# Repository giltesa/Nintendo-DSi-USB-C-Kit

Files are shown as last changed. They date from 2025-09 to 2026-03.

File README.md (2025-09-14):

# Nintendo DSi USB-C

The **Nintendo DSi: USB-C** is a board that allows to replace the original charging connector for a modern and standard **USB-C**.

**If your original connector is too old or damaged** and you need a new one, or **if you would like to charge your Nintendo DSi with a standard USB-C charger**, like the charger of your **Nintendo Switch**, phone, laptop, you can with this board.

This board is compatible with these models:

*   Nintendo DSi
*   Nintendo DSi XL

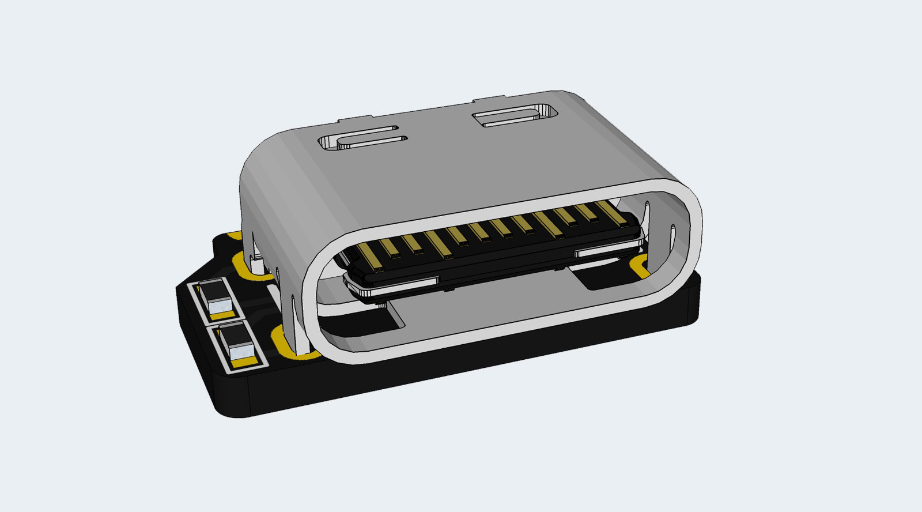
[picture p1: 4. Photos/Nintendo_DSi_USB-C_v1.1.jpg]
Nintendo-DSi-USB-C


## Would you like it?

https://shop.giltesa.com/product/nintendo-DSi-usb-c-kit/

## More

- [giltesa.com](https://giltesa.com "giltesa.com")
- [twitter.com](https://twitter.com/giltesa "twitter.com")

## License

This project is licensed under a **Creative Commons** license:
**[Attribution-NonCommercial-ShareAlike 4.0 International (CC BY-NC-SA 4.0) ](https://creativecommons.org/licenses/by-nc-sa/4.0/)**

Check the [LICENSE.md](LICENSE.md) for more information.

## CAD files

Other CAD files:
2. Renders, 3D models/Nintendo DSi USB-C - DATA v1.0.skp
2. Renders, 3D models/Nintendo DSi USB-C v1.0.skp
2. Renders, 3D models/Nintendo DSi USB-C v1.1.skp

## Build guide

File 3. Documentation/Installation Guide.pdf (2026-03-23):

# USB-C KIT For

# Nintendo DSi Nintendo DSi XL

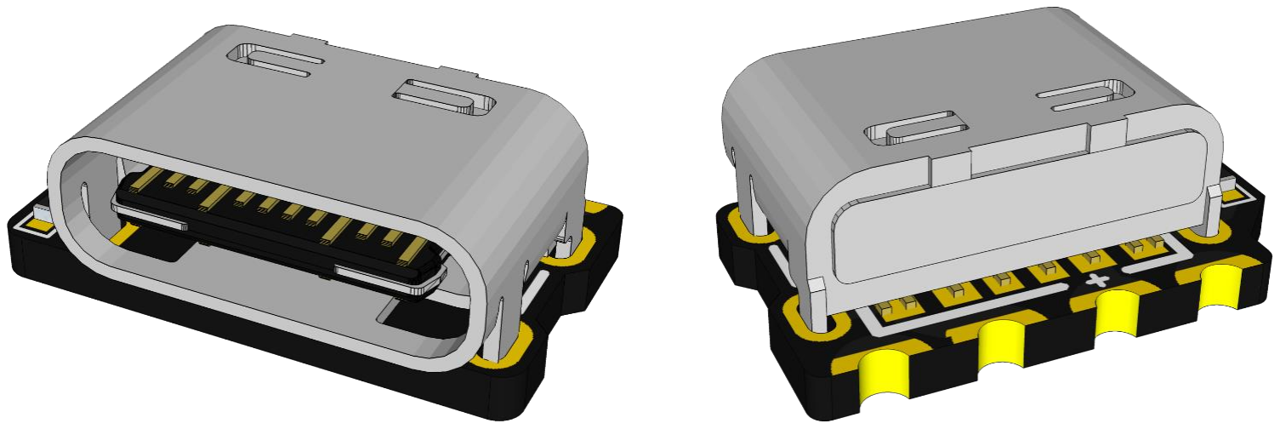
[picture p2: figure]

### PRODUCT

HTTPS://SHOP.GILTESA.COM/PRODUCT/NINTENDO-DSi-USB-C-KIT

# PLEASE READ THROUGH THESE INSTRUCTIONS

ENTIRELY BEFORE ATTEMPTING TO INSTALL.

# WARNING: IF YOU ARE NOT COMFORTABLE WITH SOLDERING, OR PERFORMING ANY STEP IN THIS

GUIDE, DO NOT PERFORM THE INSTALL YOURSELF.

# FIND SOMEONE WHO IS COMFORTABLE TO DO IT FOR

YOU.

INDEX

# Description

The Nintendo DSi: USB-C Kit is a board that allows to replace the original charging connector for a modern and standard USB-C.

If your original connector is too old or damaged and you need a new one, or if you would like to charge your Nintendo DSi with a standard USB-C charger, like the charger of your Nintendo Switch, phone, laptop, you can with this kit.

This board is compatible with these two models:

- Nintendo DSi
- Nintendo DSi XL

# FEATURES

- Charging your Nintendo with:
- USB power banks
- USB-A chargers
- USB-C chargers
- USB-C PD chargers (normal speed, not fast)
- USB-A to USB-C cables
- USB-C to USB-C cables

# INCLUDED

- 1 board.

# Recommended / REQUIRED (NOT INCLUDED)

- Phillips screwdriver
- Kapton tape
- Soldering iron
- Tin
- Flux
- Desoldering pump
- Desoldering mesh
- Isopropyl alcohol

# Board details

This tiny board has 7 pads in about 1cm²
surface, which means it requires high soldering skills. The following explains what each pad is for.

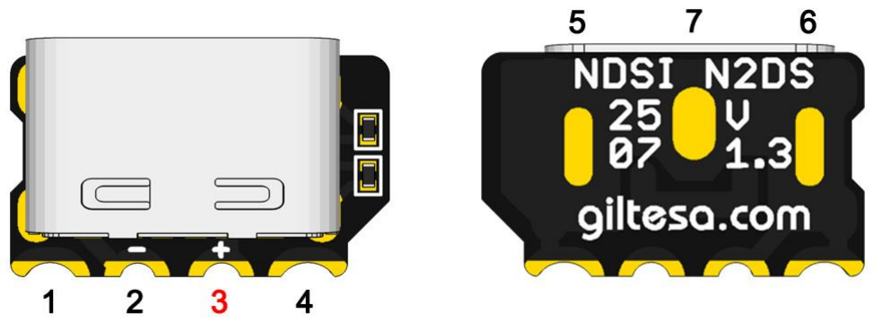
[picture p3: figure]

Nintendo DSi - Standard version.

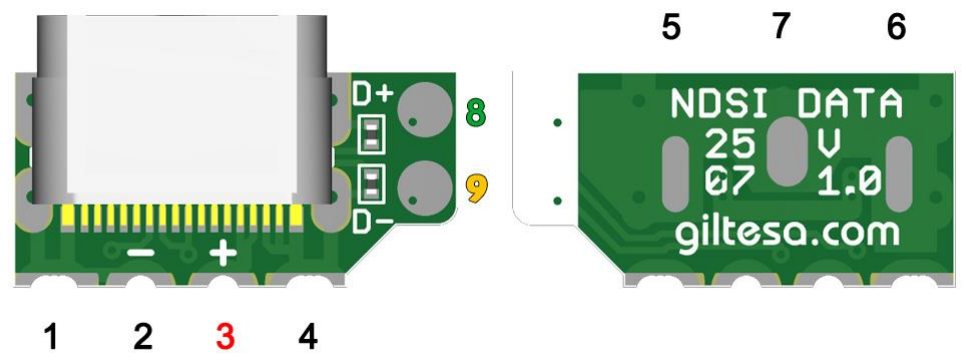
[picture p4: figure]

Nintendo 3DS DATA - With support for data connection.

Starting from the left to the right:

1. GND | The ground pad.
2. GND | The ground pad.
3. VCC | The 5V line from the USB-C.
4. GND | The ground pad.
5. GND | The ground pad.
6. GND | The ground pad.
7. GND | This ground pad is exclusive to the 2DS. Do not use it on
| the DSi.
8. D+ | Positive data pad for only DATA board model.
9. D- | Negative data pad for only DATA board model.

# Test the board!

Before starting the installation, you should test the board. If it doesn’t work contact me for a replacement (https://shop.giltesa.com/refund-policy/) (all boards are fully tested, but they may damage during the shipping, we try to package them as better as possible), if it works, go ahead with the installation.

Connect the power from your USB charger to the USB-C connector on the board. Then, with a multimeter in voltage measurement mode, check for a 5V reading. If that's the case, continue with the installation.

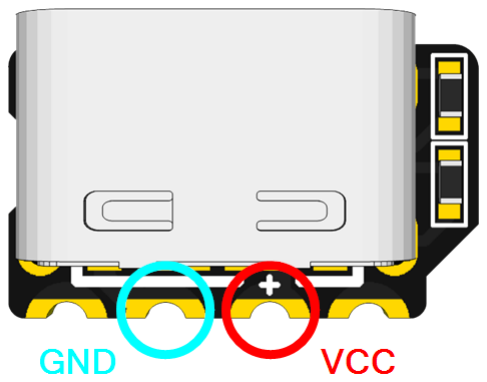
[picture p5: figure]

# INSTALLATION STEPS

Please, carefully read the following steps for a successful installation.

## Pre installation Steps

Before the installation, your Nintendo DSi may need some extra steps to have it ready for the kit.

1. Disassembly the Nintendo DSi

Nintendo DSi use the phillips screws to close the shell. First remove the two screws which hold the DSi plastic battery cover.

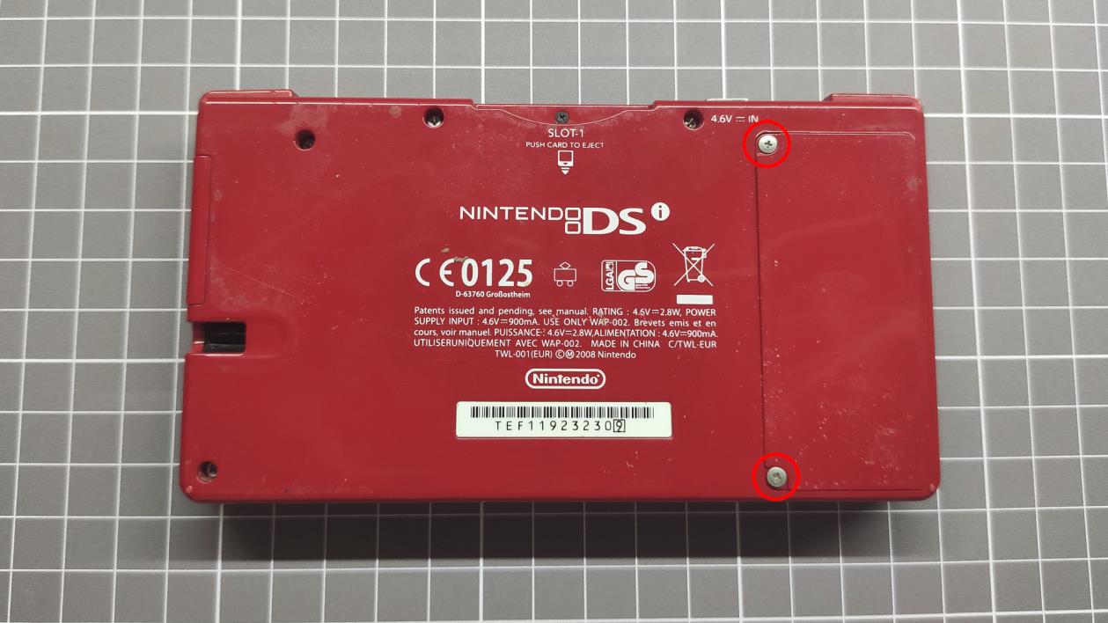
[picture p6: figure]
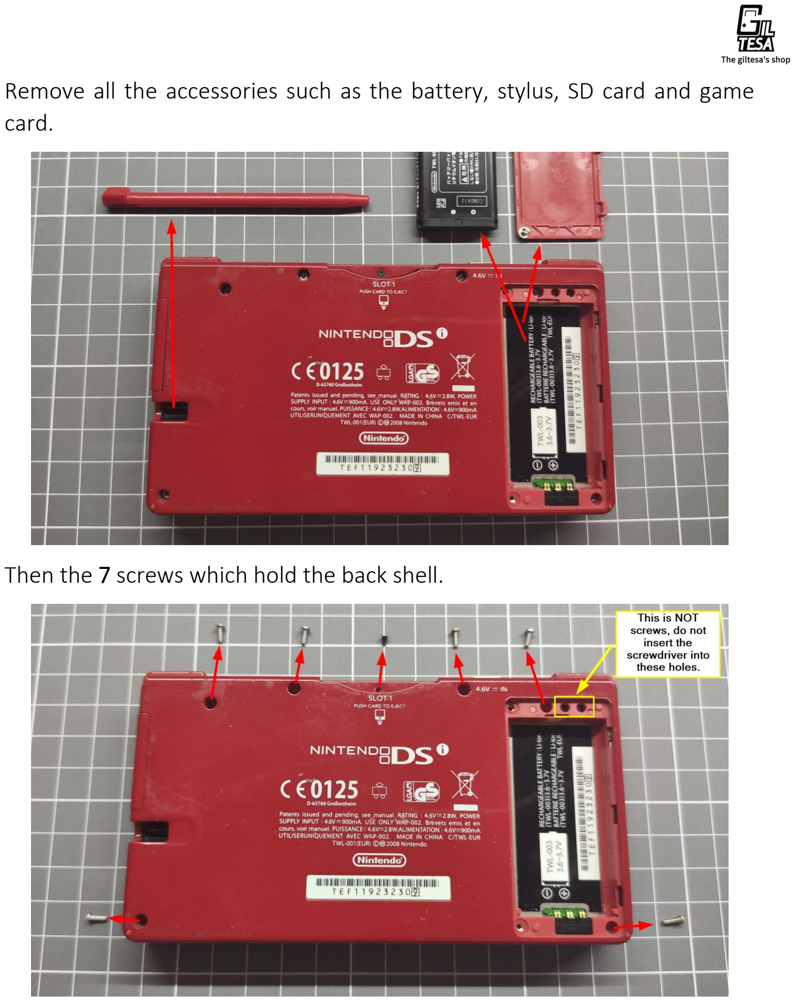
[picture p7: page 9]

Remove all the accessories such as the battery, stylus, SD card and game card.

Then the 7 screws which hold the back shell.

Open the back shell carefully because it is connected to the mainboard with one flex cable. To disconnect the flex cable, pull it upwards.

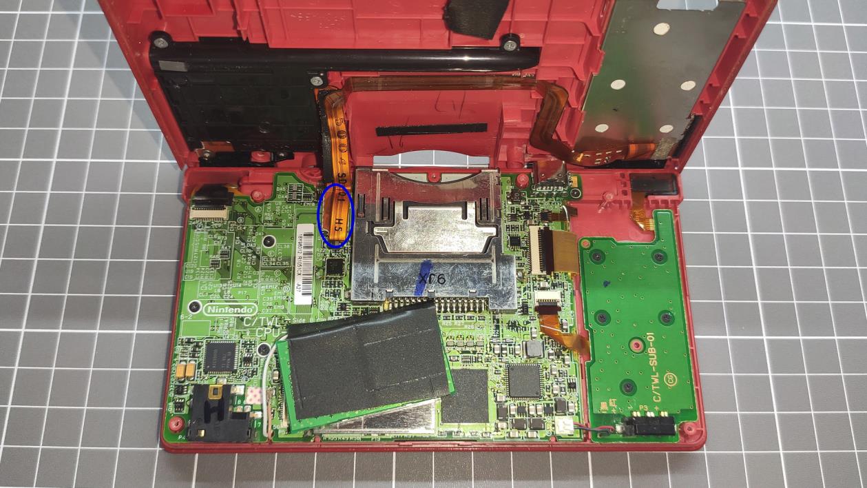
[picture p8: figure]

As you can see in the images, my Nintendo DSi already had the kit installed. I lost the photos when I was removing the original connector, but that's not a problem since it's removed in the same way.

So, I'm going to remove my test kit and install the final version, and you will have to remove the original connector and install the kit.

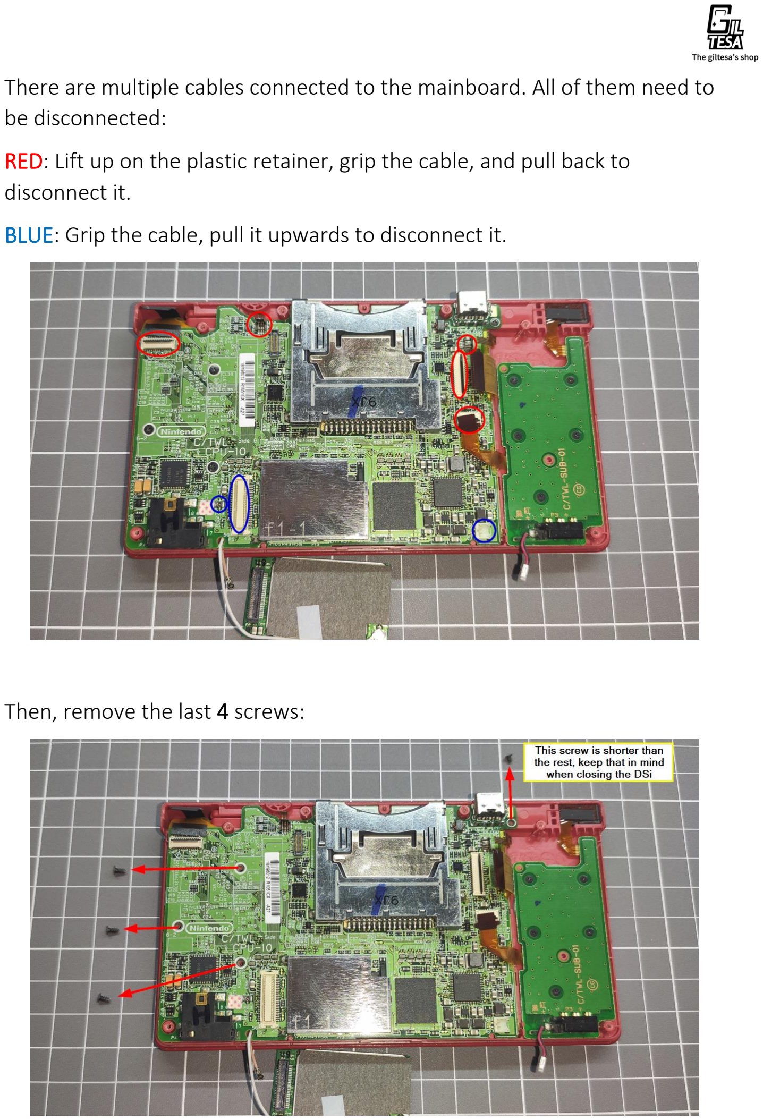
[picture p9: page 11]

There are multiple cables connected to the mainboard. All of them need to be disconnected:

RED: Lift up on the plastic retainer, grip the cable, and pull back to disconnect it.

BLUE: Grip the cable, pull it upwards to disconnect it.

Then, remove the last 4 screws:

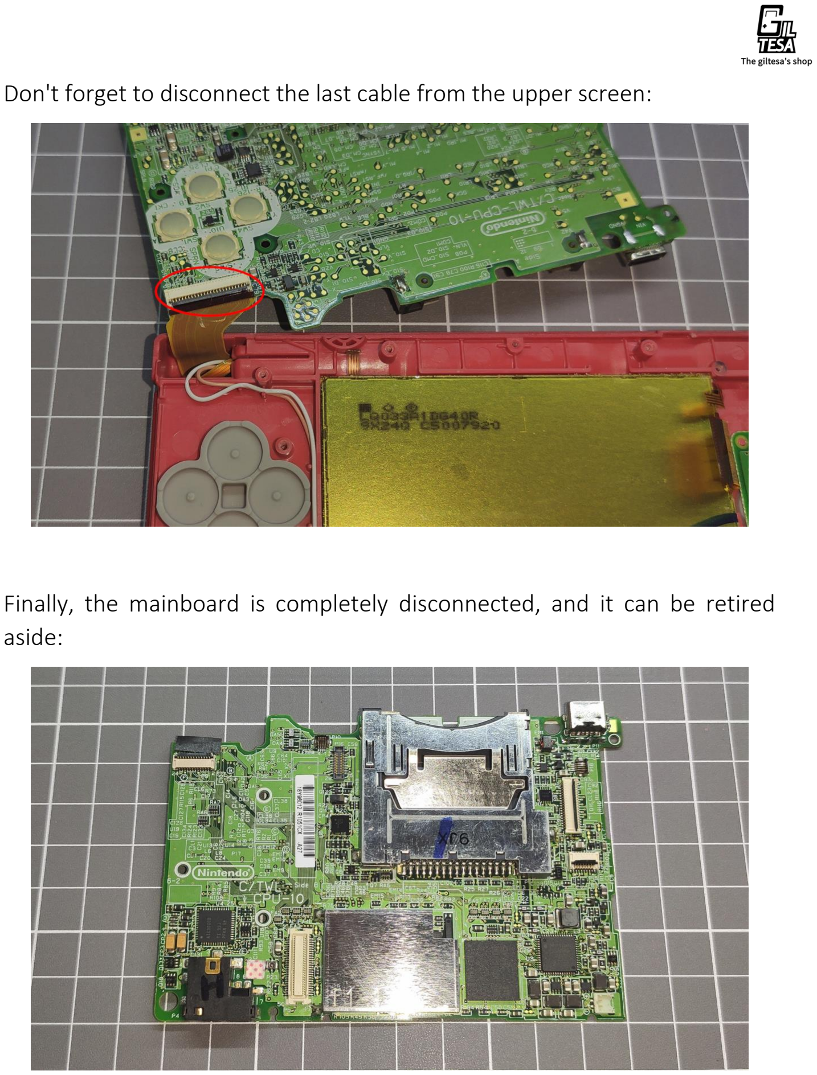
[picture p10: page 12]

Don't forget to disconnect the last cable from the upper screen:

Finally, the mainboard is completely disconnected, and it can be retired aside:

## installation Steps

1. Protect the nearest components

Use Kapton tape to protect and avoid any damage to the electronic components that are next to the connector.

2. Remove unnecessary components

This kit only requires removing the power connector. However, it has many legs, and it may be hard to remove.

If you have an air solder station, you can remove it easily, but protect perfect the nearest places with Kapton tape or something may be burn.

Otherwise, the recommendation is using a desoldering pump which will help to remove the tin from each hole/pad.

3. Clean the board

After the component is removed, it may be dirty, clean both sides.

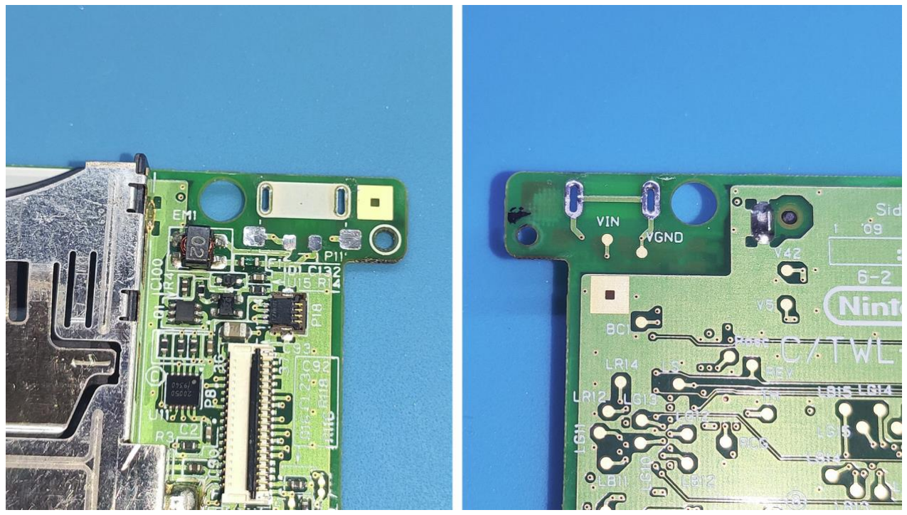
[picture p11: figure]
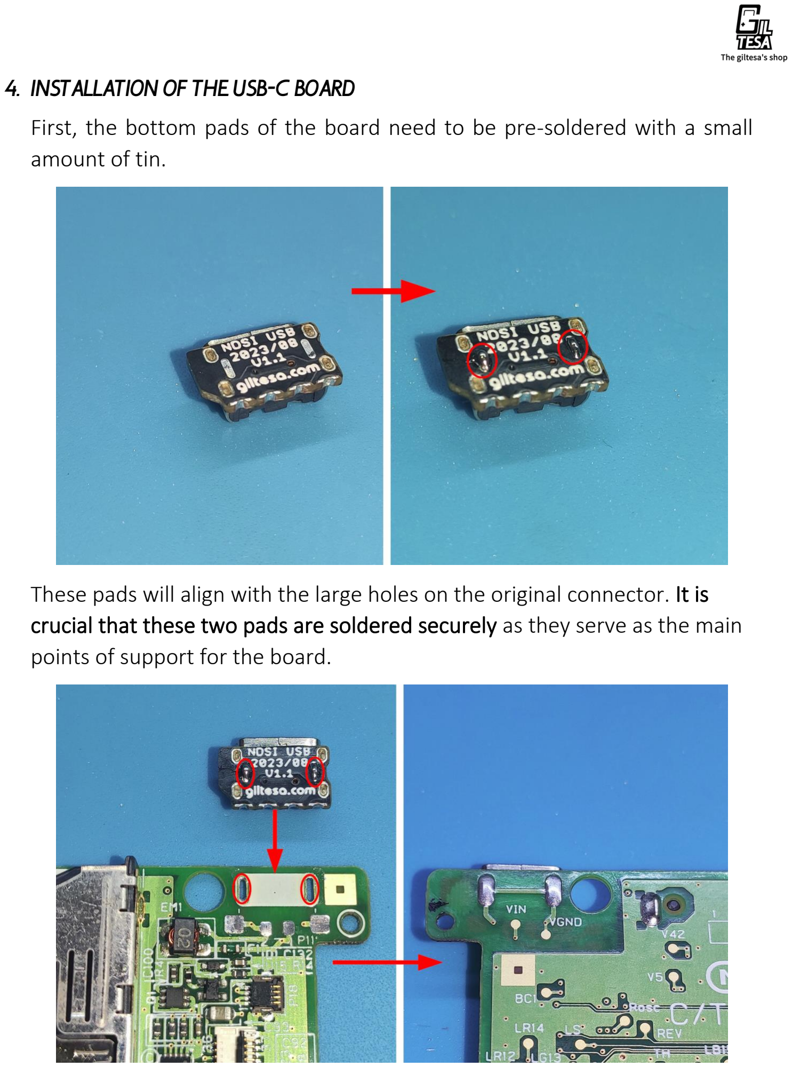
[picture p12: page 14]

4. Installation of the USB-C board

First, the bottom pads of the board need to be pre-soldered with a small amount of tin.

These pads will align with the large holes on the original connector. It is crucial that these two pads are soldered securely as they serve as the main points of support for the board.

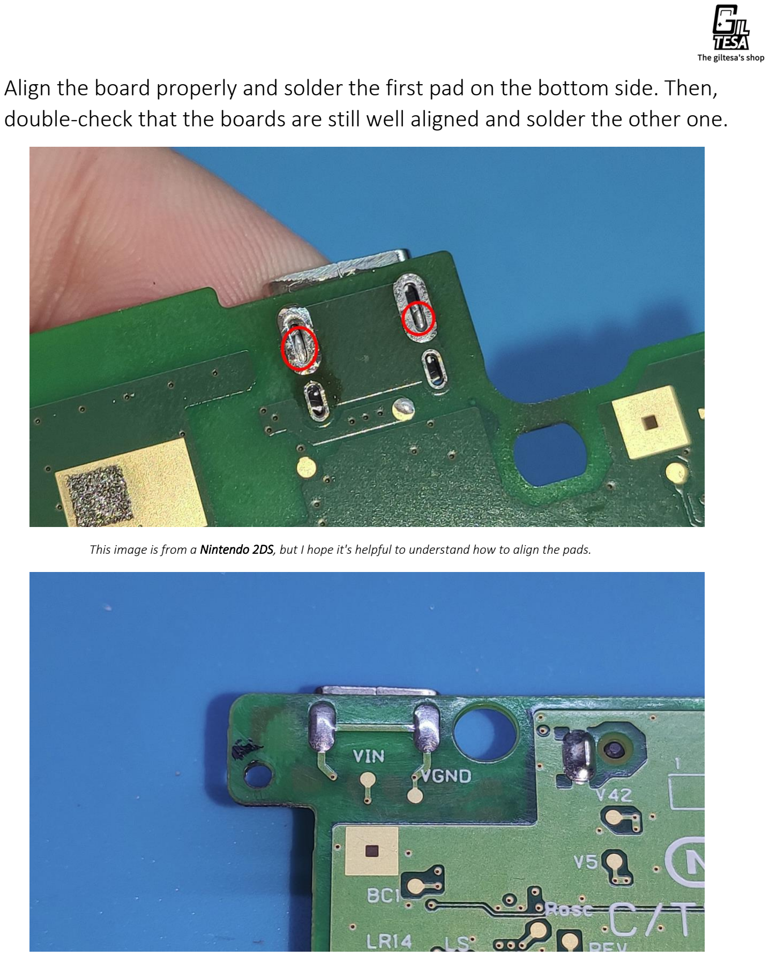
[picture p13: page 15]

Align the board properly and solder the first pad on the bottom side. Then, double-check that the boards are still well aligned and solder the other one.

This image is from a Nintendo 2DS, but I hope it's helpful to understand how to align the pads.

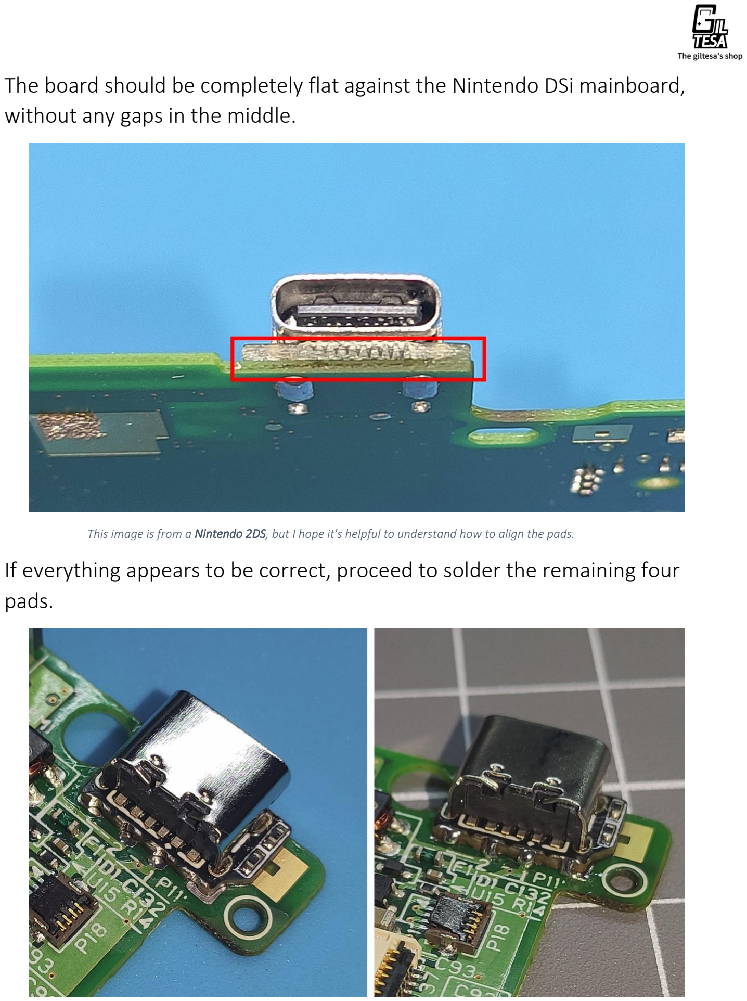
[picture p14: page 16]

The board should be completely flat against the Nintendo DSi mainboard, without any gaps in the middle.

This image is from a Nintendo 2DS, but I hope it's helpful to understand how to align the pads.
If everything appears to be correct, proceed to solder the remaining four pads.

Optionally, the front side can be painted with a permanent black marker.

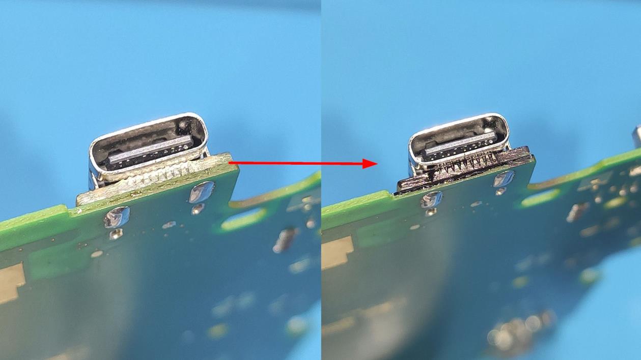
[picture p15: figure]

This image is from a Nintendo 2DS, but I hope it's helpful to understand how to align the pads.

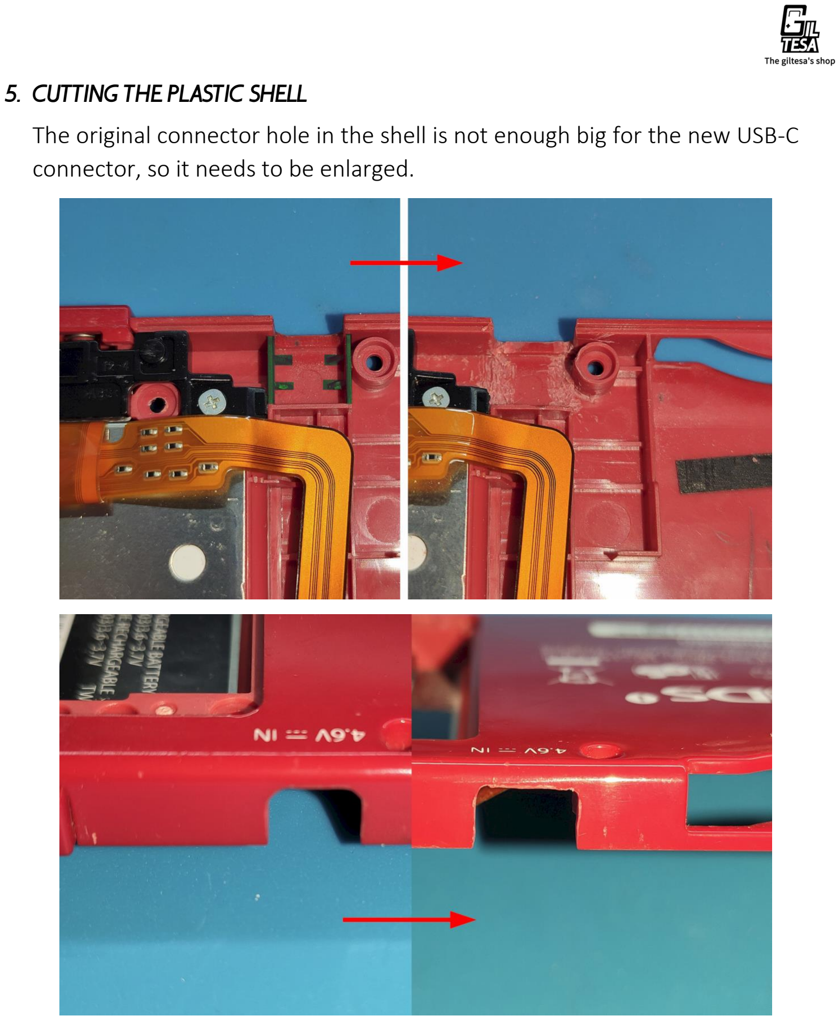
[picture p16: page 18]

5. Cutting the plastic shell

The original connector hole in the shell is not enough big for the new USB-C connector, so it needs to be enlarged.

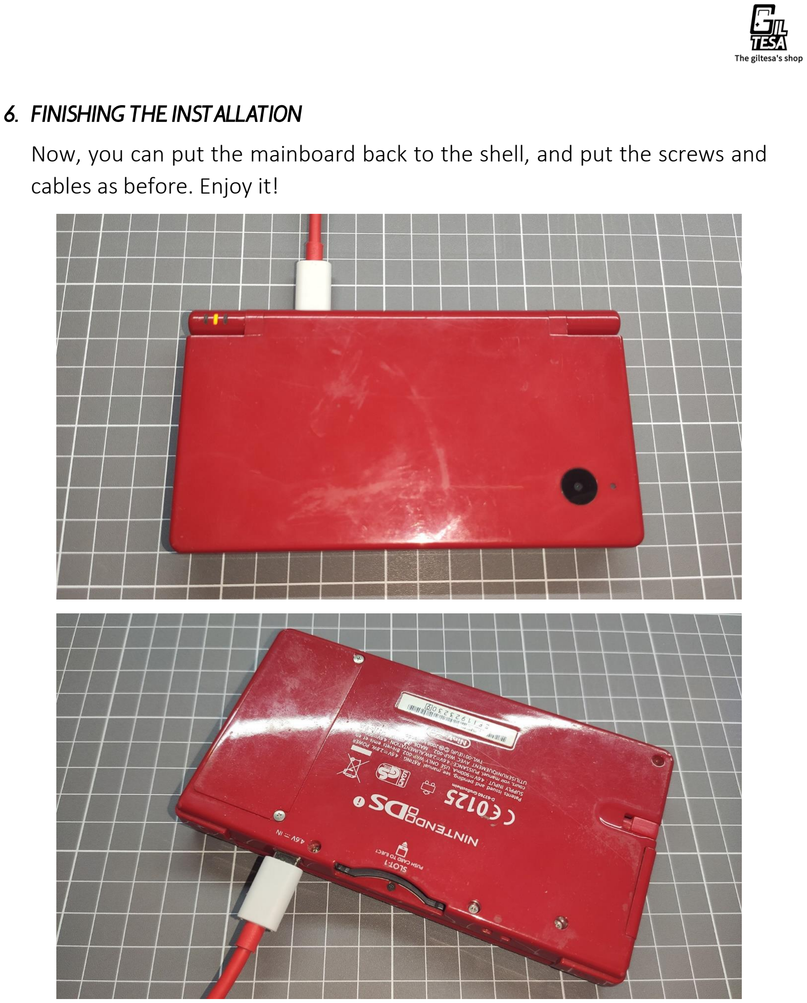
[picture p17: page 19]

6. Finishing the installation

Now, you can put the mainboard back to the shell, and put the screws and cables as before. Enjoy it!

# Nintendo DSi DATA - With support for data connection

This specific version of the board supports data connection via USB-C, not just power like the standard version.

This feature is for very specific use cases. Essentially, it allows some mod installed inside the console to use the USB-C connector to transmit data to a computer. The most typical use is when a video capture card is installed to record on the computer what is displayed on the console screens. Instead of using an extra connector, the same one can be used for everything: charging the console and transmitting data.

Given that I do not have a video capture card, I am showing a test performed with an SD card reader connected to the computer. This is simply a test, not a real use case. This product can never be used to access the console's MicroSD.

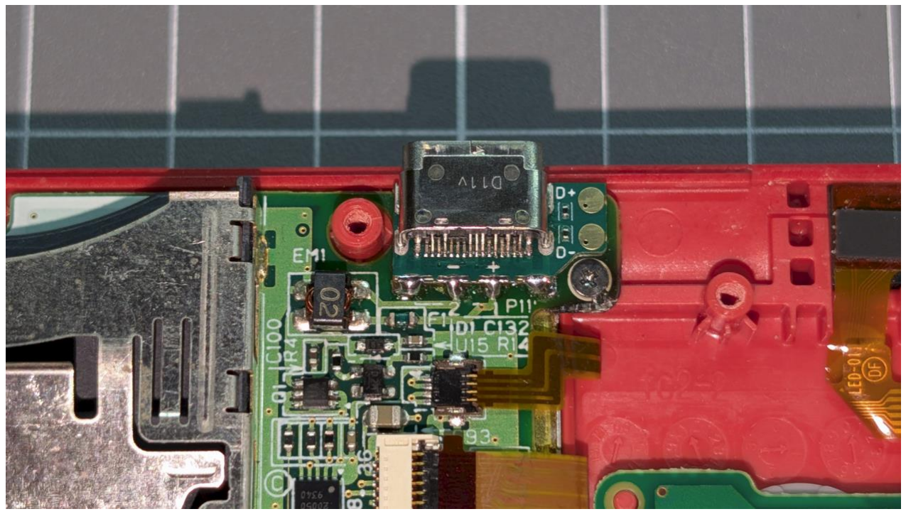
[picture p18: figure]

# Frequently Asked Questions - FAQ

What charger can be used?
You can use any standard charger for mobile phones, computers, etc., with 5V 1A. It doesn't need to be a Power Delivery charger since this feature is not used. Of course, if you want to use a Power Delivery charger, there's no problem or risk.

Technical data for curious minds:

Power Delivery chargers can supply a wide range of voltages: 5V, 9V, 12V, 15V, and 20V. However, for this to happen, the device must communicate with the charger to explicitly request the desired voltage. Without this communication, the charger will never supply more than 5V. That's one of the advantages of USB-C, as it can be used with both old and modern devices.

My console does not turn on or does not charge!
Since installing the USB-C requires almost completely disassembling the console, it is possible that when reassembling it, some flexible cable was not properly connected, such as the screen cable, touch screen, etc.

If any of the cables are not properly connected, the console may turn on its status LED for a second and then turn off, do nothing, or it may not even start charging.

Check that you have connected all the cables to their connectors and that they are properly inserted. That should solve the problem.

The console still does not turn on.
So, if the previous steps did not solve it, you should check that the fuses have not blown. This can happen especially if a short circuit occurs during installation and you connect the power or the battery.

You can use a multimeter in continuity mode to check if the fuse has continuity and is therefore in good condition.

If the fuses have blown, the correct solution is to replace them with new ones. They are usually easy to find on AliExpress or from spare parts resellers.
